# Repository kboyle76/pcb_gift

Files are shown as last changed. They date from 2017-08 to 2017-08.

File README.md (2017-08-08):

# pcb_gift

This is a soldering kit for to be distributed at the Playa Circuit Booogie Camp at Burning Man 2017. Our goal was to design a soldering kit that does something a little bit more interesting than simply blinking lights while still costing less than a few dollars each. Only one color LED is initally lit after assembling the kit, and users must find another person to "share" their color with and receive new colors in return to light up the rest of the LEDs! Each device can only receive one color from each other device, and communication happens using infrared light.

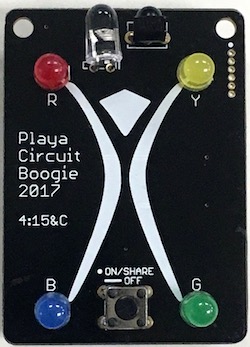
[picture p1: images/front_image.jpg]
Assembled Board Front
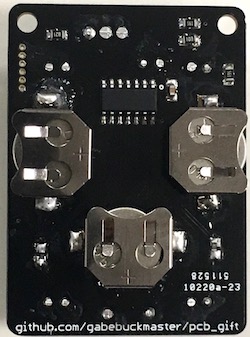
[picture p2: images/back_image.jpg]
Assembled Board Back
 

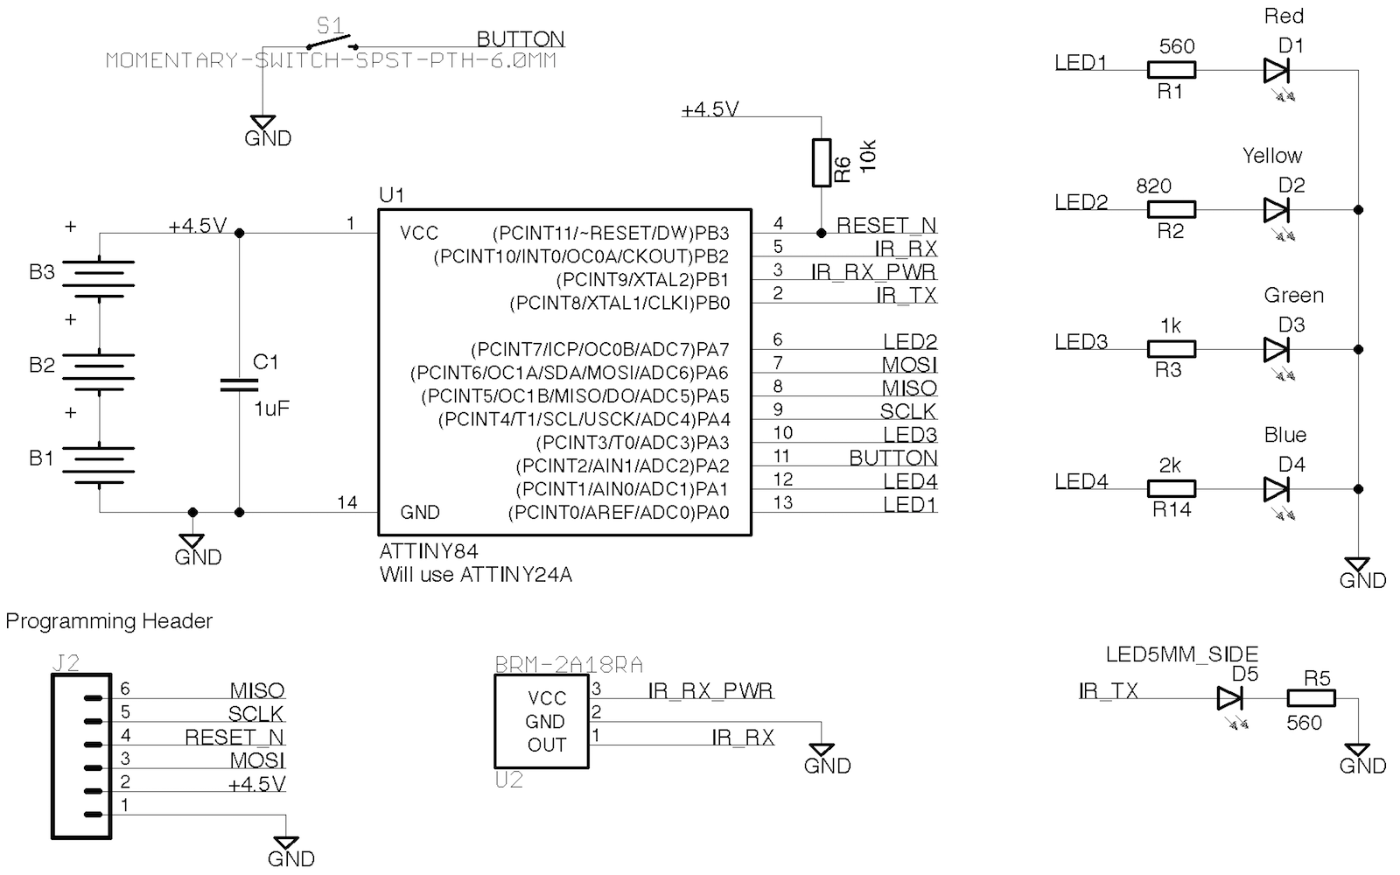
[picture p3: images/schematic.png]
Schematic


### SMT Pre-assembly Notes
The surface mount components will be pre-populated to facilitate assembly at the Playa.
- The surface mount battery holders are a bit weak and tend to pop off the circuit board, sometimes bringing the pad with them. You may want to further secure them with a dab of epoxy.
- For aesthetic reasons, surface mount component names are not included in the bottom silkscreen. The component locations are shown below for your convenience. 

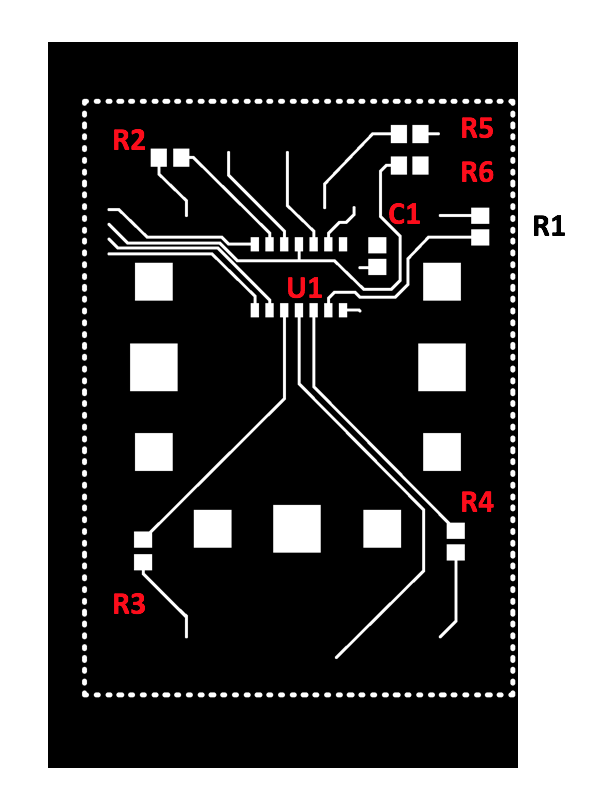
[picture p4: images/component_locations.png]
Component Locations


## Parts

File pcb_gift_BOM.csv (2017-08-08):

Reference | Quantity | Description | Manufacturer | Part Number | Cost @ qty 100 | Extended cost | Notes
U1 | 1 | 8 bit microcontroller -12 GPIO, 14 SOIC | Microchip | ATTINY44A-SSU | 0.618 | 61.8 | Digikey
U2 | 1 | 38 kHz IR receiver | Vishay | TSOP38338 | 0.6 | 60 | Digikey
C1 | 1 | 1uF 0805 ceramic capacitor X5R 6.3V | Generic |  | 0.0093 | 0.93 | Digikey
S1 | 1 | Tactile pushbutton | Generic |  | 0.04 | 8 | Aliexpress
R1, R5 | 2 | 5% 0805 Resistor 560 Ohms | Generic |  | 0.0067 | 1.34 | Digikey
R2 | 1 | 5% 0805 Resistor 820 Ohms | Generic |  | 0.0067 | 0.67 | Digikey
R3 | 1 | 5% 0805 Resistor 1.2k Ohms | Generic |  | 0.0067 | 0.67 | Digikey
R4 | 1 | 5% 0805 Resistor 680 Ohms | Generic |  | 0.0067 | 0.67 | Digikey
R6 | 1 | 5% 0805 Resistor 10k Ohms | Generic |  | 0.0067 | 0.67 | Digikey
D1 | 1 | 5mm Red Led | Generic |  | 0.0181 | 1.81 | Aliexpress
D2 | 1 | 5mm Yellow Led | Generic |  | 0.0181 | 1.81 | Aliexpress
D3 | 1 | 5mm Green Led | Generic |  | 0.0181 | 1.81 | Aliexpress
D4 | 1 | 5mm Blue Led | Generic |  | 0.0181 | 1.81 | Aliexpress
D5 | 1 | IR LED transmitter | Generic |  | 0.0181 | 1.81 | Aliexpress
B1-3 | 3 | Battery holder | Keystone | 2996 | 0.20492 | 61.476 | Digikey
N/A | 3 | LR44 battery |  |  | 0.0788 | 23.64 | Amazon

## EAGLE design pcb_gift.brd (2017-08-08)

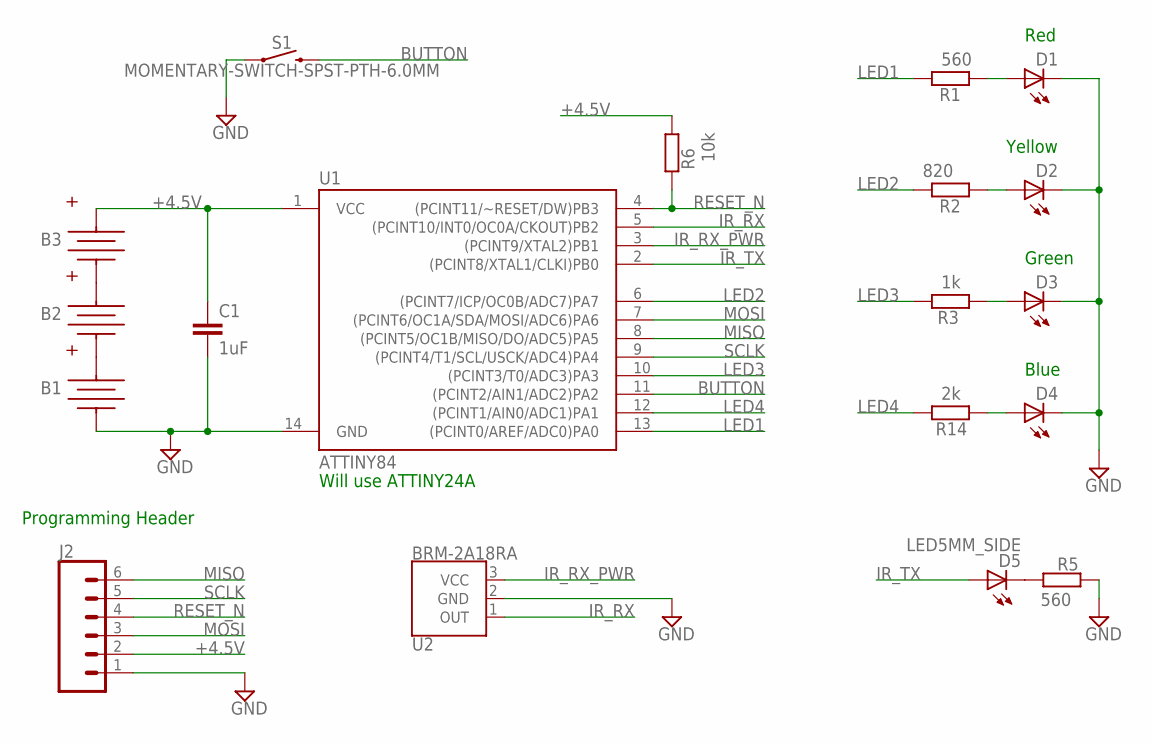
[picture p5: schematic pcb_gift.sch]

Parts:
B1, B2, B3: KEYSTONE_2996
C1: 1uF; C0805
D1, D2, D3, D4: LED5MM
D5: LED5MM_SIDE
J2: CONN_061.27MM; 1X06_1.27MM
R1, R5: 560; R0805
R2: 820; R0805
R3: 1k; R0805
R6: 10k; R0805
R14: 2k; R0805
S1: MOMENTARY-SWITCH-SPST-PTH-6.0MM; TACTILE_SWITCH_PTH_6.0MM
U1: ATTINY84; SO14
U2: BRM-2A18RA; BRM-2508

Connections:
+4.5V: B3.POSA (POS), B3.POSB (POS), C1.1, J2.2, R6.2, U1.1 (VCC)
BUTTON: S1.3 (2), U1.11 ((PCINT2/AIN1/ADC2)PA2)
GND: B1.NEG, C1.2, D1.K (C), D2.K (C), D3.K (C), D4.K (C), J2.1, R5.1, S1.1, U1.14 (GND), U2.2 (GND)
IR_RX: U1.5 ((PCINT10/INT0/OC0A/CKOUT)PB2), U2.1 (OUT)
IR_RX_PWR: U1.3 ((PCINT9/XTAL2)PB1), U2.3 (VCC)
IR_TX: D5.A, U1.2 ((PCINT8/XTAL1/CLKI)PB0)
LED1: R1.1, U1.13 ((PCINT0/AREF/ADC0)PA0)
LED2: R2.1, U1.6 ((PCINT7/ICP/OC0B/ADC7)PA7)
LED3: R3.1, U1.10 ((PCINT3/T0/ADC3)PA3)
LED4: R14.1, U1.12 ((PCINT1/AIN0/ADC1)PA1)
MISO: J2.6, U1.8 ((PCINT5/OC1B/MISO/DO/ADC5)PA5)
MOSI: J2.3, U1.7 ((PCINT6/OC1A/SDA/MOSI/ADC6)PA6)
unnamed: D1.A, R1.2
unnamed: B1.POSA (POS), B1.POSB (POS), B2.NEG
unnamed: B2.POSA (POS), B2.POSB (POS), B3.NEG
unnamed: D4.A, R14.2
unnamed: D3.A, R3.2
unnamed: D2.A, R2.2
unnamed: D5.K (C), R5.2
RESET_N: J2.4, R6.1, U1.4 ((PCINT11/~RESET/DW)PB3)
SCLK: J2.5, U1.9 ((PCINT4/T1/SCL/USCK/ADC4)PA4)

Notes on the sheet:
Will use ATTINY24A
Programming Header
Red
Yellow
Green
Blue

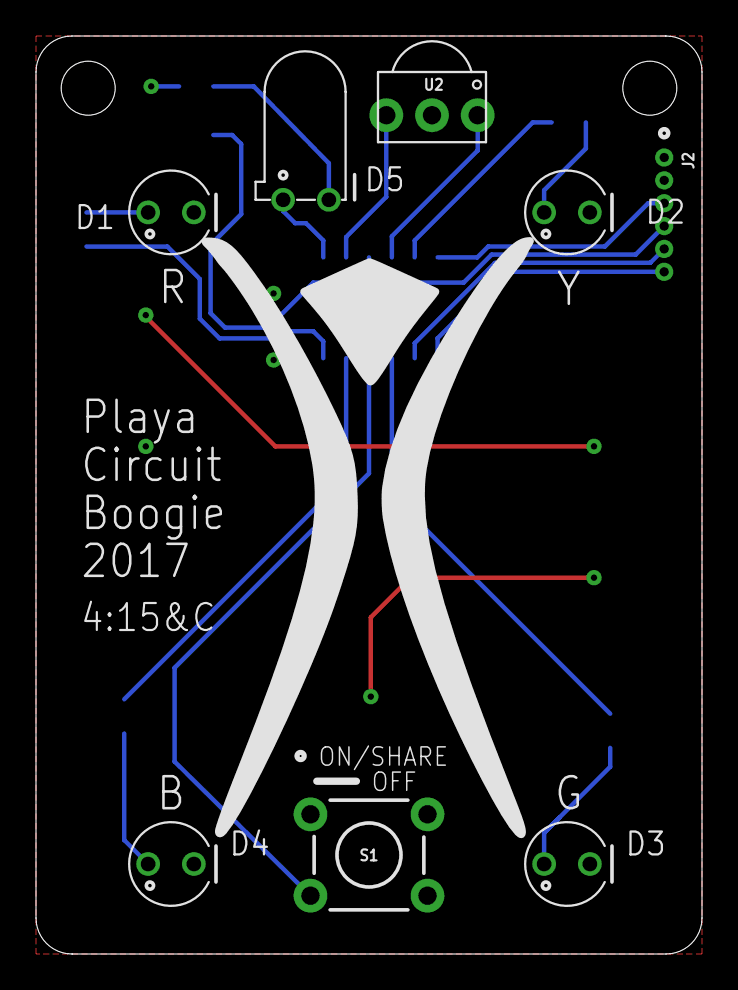
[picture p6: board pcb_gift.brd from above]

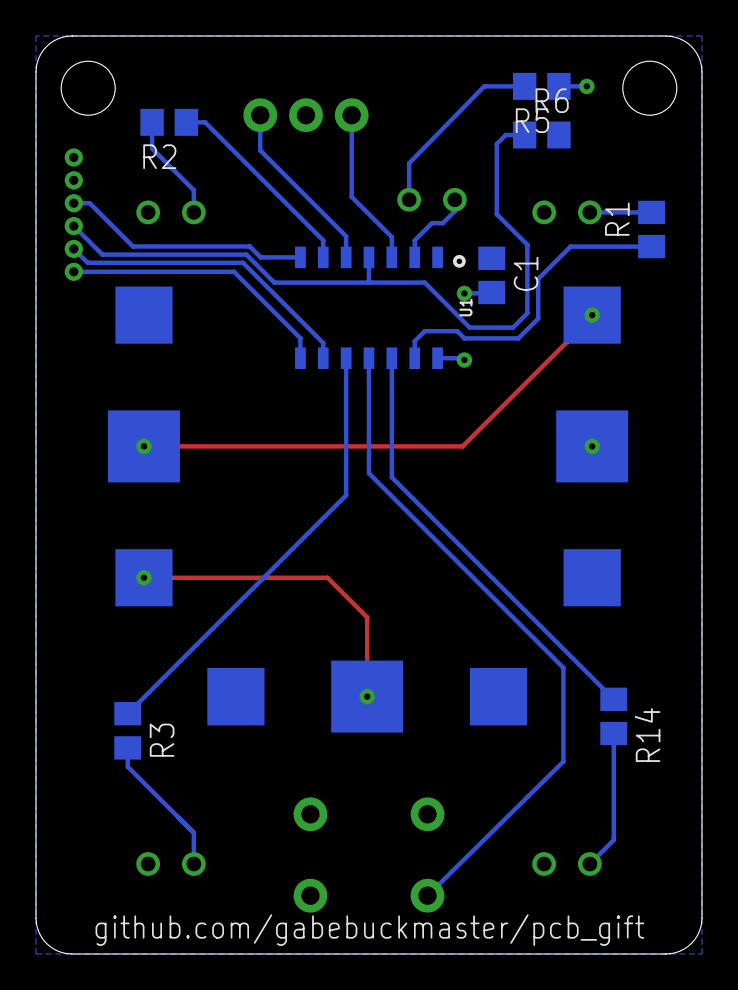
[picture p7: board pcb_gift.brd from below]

Board: 2 copper layers, 37.0 x 51.0 mm, 19 parts (11 on the bottom side), 21 nets.

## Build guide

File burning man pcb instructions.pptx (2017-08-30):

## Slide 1

Playa Circuit Boogie

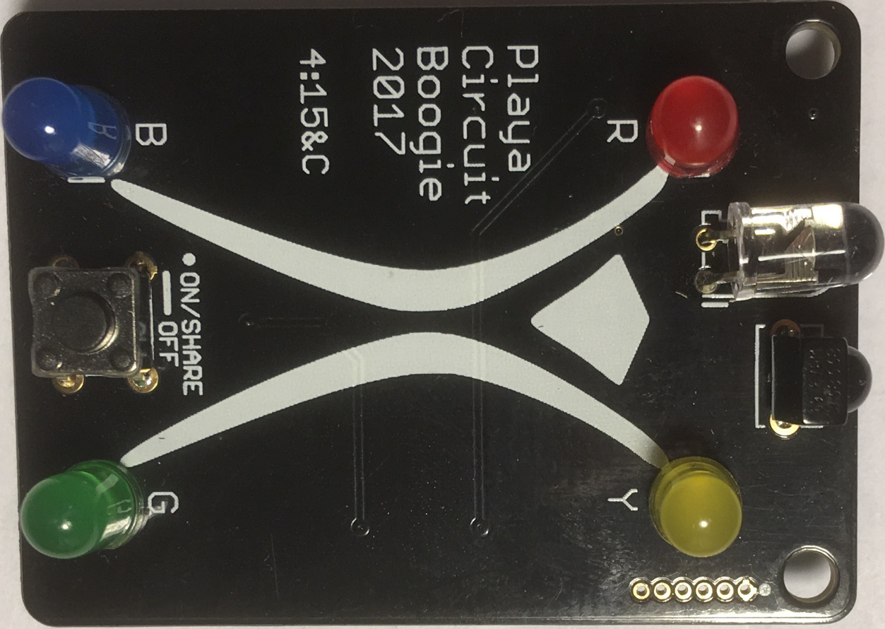
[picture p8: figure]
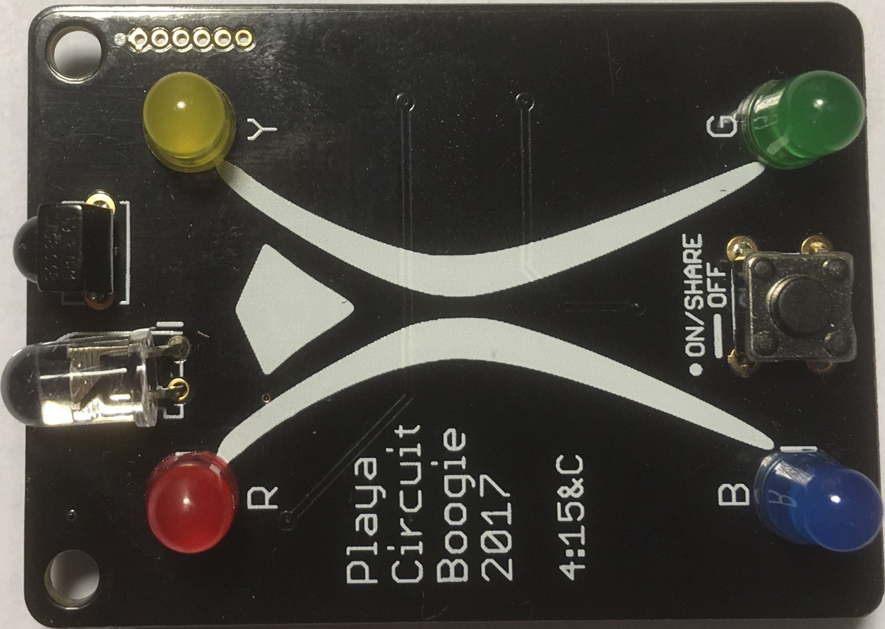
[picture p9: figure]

These instructions will help you solder together your very own PCB color widget so you can collect all four colors and light up the Man!
Just like a puzzle box, the picture above shows the final product, follow the instructions on the back and refer to this picture to put it together.
Once you’re done, and pop in the batteries, the lights should start flashing, press the button once to get your first color. Then:
- Find someone with a color you don’t yet have
- Point the clear and black LEDs facing outward on the two PCBs towards each other (like above) and press the buttons once at the same time
- You’ll get a color you don’t have that your new friend does. If multiple colors blink, then you don’t have any of those: press the button once to decide which one you get
- If you have a color your new friend doesn’t have, they’ll get that color
- You can only trade colors with a person once! If you try again, your PCB will flash the color you got from them already to remind you
- Hold the button briefly until the lights go out to turn off. Press once to turn back on. Save it for the nighttime! If the batteries die, it will still remember what colors you have, so come back around and see if we have spares
- If something goes terribly wrong, hold the button for about 30 seconds, until the lights start flashing again. This will reset you all the way back to the default
- If you love this project and want to check out how we did it, follow the link printed on the back of the PCB when you get home
Have fun and try to collect all the colors (and three new friends)!

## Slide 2

1
Start with the clear LED, this is the IR transmitter. Slot it into the correct holes (see tip below), and bend it over 90 degrees to face out, like the outline shows. Solder this from the back.
Tip: the symbols on the board show a dot for where the longer leg goes, and a flat bar that corresponds to the flat edge of the LED.

Front

2
Second, solder on the IR receiver. The bump should face outward. If it ends up crooked, gently bend it to be straight up and down.

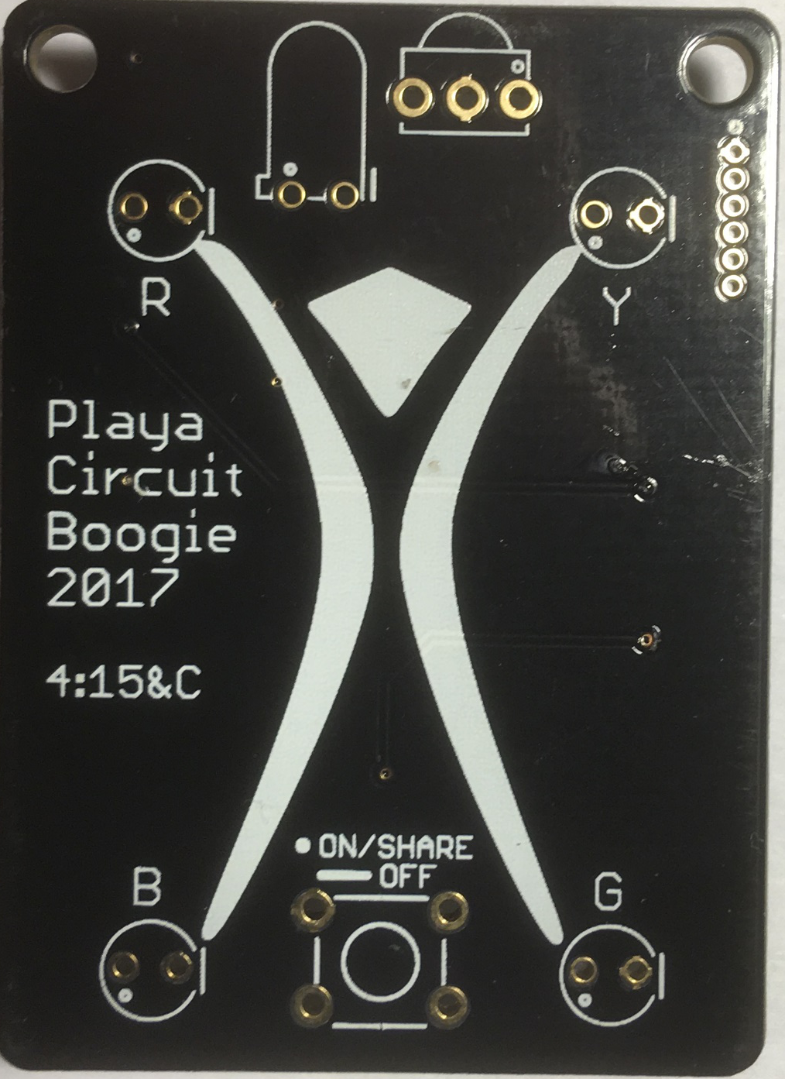
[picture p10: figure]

3
Third, solder the button. It has four legs and only fits on in one orientation: with the legs on the left and right sides, not the top and bottom sides. The bottom two connections are mandatory, the top two are optional.

4
Fourth, put each colored LED in its corresponding place, R – Red, Y – Yellow, B – Blue, G – Green. Pay attention to the tip above to get them in the right orientation. If you mix and match the positions, some LEDs may be brighter or dimmer, or not turn on at all!

5
Clip off the ends of the legs at the base while firmly holding on: avoid eye damage and MOOP from flying parts! Insert three batteries into the metal holders on the back. The lights should start flashing, press the button to get your first color!

Back

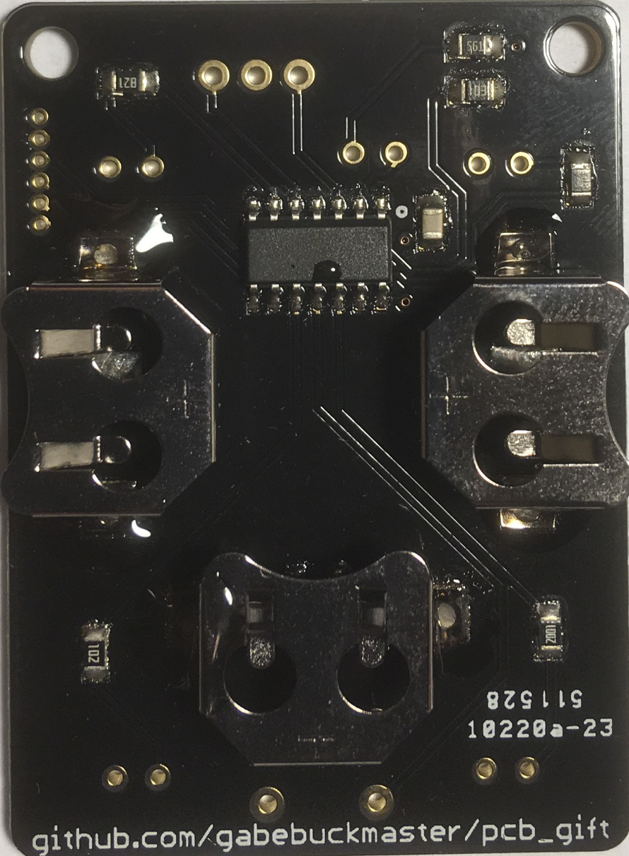
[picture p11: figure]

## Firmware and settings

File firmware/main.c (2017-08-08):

#include <avr/io.h>
#include <avr/interrupt.h>
#include <avr/sleep.h>
#include <avr/wdt.h>

#define IR_RX_TIMEOUT 20000

// Port A Pins
#define RED_LED 0
#define YELLOW_LED 7
#define GREEN_LED 3
#define BLUE_LED 1

#define RED_LED_COMM 0
#define YELLOW_LED_COMM 2
#define GREEN_LED_COMM 3
#define BLUE_LED_COMM 1

#define BUTTON 2


// Port B Pins
#define IR_TX 0
#define IR_RX_POWER 1
#define IR_RX 2


uint8_t my_colors = 0;
uint16_t my_id = 0;
uint16_t red_source_id = 0;
uint16_t green_source_id = 0;
uint16_t blue_source_id = 0;
uint16_t yellow_source_id = 0;


void stop_timer(void)
{
    cli();
    TCCR1A = 0;
    TCCR1B = 0;
    TIMSK1 = 0;
    sei();
}

void EEPROM_write(uint8_t address, uint8_t data)
{
    /* Wait for completion of previous write */
    while(EECR & (1<<EEPE));
    /* Set Programming mode */
    EECR = (0<<EEPM1)|(0<<EEPM0);
    /* Set up address and data registers */
    EEAR = address;
    EEDR = data;
    /* Write logical one to EEMPE */
    EECR |= (1<<EEMPE);
    /* Start eeprom write by setting EEPE */
    EECR |= (1<<EEPE);
}

uint8_t EEPROM_read(uint8_t address) {
    /* Wait for completion of previous write */
    while(EECR & (1<<EEPE));
    /* Set up address register */
    EEAR = address;
    /* Start eeprom read by writing EERE */
    EECR |= (1<<EERE);
    /* Return data from data register */
    return EEDR;
}

void erase_state(void)
{
    for(uint8_t i = 0; i < 11; i++)
    {
        EEPROM_write(i, 0xFF);
    }
}

void save_state(void)
{
    EEPROM_write(0, my_colors);
    EEPROM_write(1, my_id>>8);
    EEPROM_write(2, my_id);
    EEPROM_write(3, red_source_id>>8);
    EEPROM_write(4, red_source_id);
    EEPROM_write(5, green_source_id>>8);
    EEPROM_write(6, green_source_id);
    EEPROM_write(7, blue_source_id>>8);
    EEPROM_write(8, blue_source_id);
    EEPROM_write(9, yellow_source_id>>8);
    EEPROM_write(10, yellow_source_id);
}

void restore_state(void)
{
    my_colors = EEPROM_read(0);
    my_id = (((uint16_t)EEPROM_read(1))<<8) + EEPROM_read(2);
    red_source_id = (((uint16_t)EEPROM_read(3))<<8) + EEPROM_read(4);
    green_source_id = (((uint16_t)EEPROM_read(5))<<8) + EEPROM_read(6);
    blue_source_id = (((uint16_t)EEPROM_read(7))<<8) + EEPROM_read(8);
    yellow_source_id = (((uint16_t)EEPROM_read(9))<<8) + EEPROM_read(10);
}

void delay(uint16_t ms)
{
    set_sleep_mode(SLEEP_MODE_IDLE);
    sei();
    for(uint16_t i = 0; i < ms/16; i++)
    {
        WDTCSR |= (1<<WDIE);
        sleep_enable();
        sleep_mode();
    }
    WDTCSR &= ~(1<<WDIE);
}

void delay_100us(uint16_t t)
{
    for (uint16_t i = 0; i < t; i++)
    {
        for(uint16_t j = 0; j < 91; j++)
        {
            __asm__ __volatile__ ("nop");
        }
    }
}

uint8_t roulette(uint8_t options)
{
    uint8_t led = (1<<BLUE_LED);
        
    //button might still be down from reset - wait for it to be released
    while(!(PINA & (1<<BUTTON)))
    {
        PORTA |= ((1<<BLUE_LED)|(1<<RED_LED)|(1<<YELLOW_LED)|(1<<GREEN_LED));
    }
    
    // display roulette pattern until button pressed
    while(PINA & (1<<BUTTON))
    {
        switch (led)
        {
            case (1<<BLUE_LED):
                led = (1<<RED_LED);
                break;
            case (1<<RED_LED):
                led = (1<<YELLOW_LED);
                break;
            case (1<<YELLOW_LED):
                led = (1<<GREEN_LED);
                break;
            case (1<<GREEN_LED):
                led = (1<<BLUE_LED);
                break;
        }
        if(led & options)
        {
            PORTA &= ~((1<<BLUE_LED)|(1<<RED_LED)|(1<<YELLOW_LED)|(1<<GREEN_LED));
            PORTA |= led;
            delay(50);
        }
    }
    // wait for button to be released and debounce before returning
    while(!(PINA & (1<<BUTTON)));
    delay(100);
    return led;
}

void ir_tx_bit(uint8_t bit)
{
    cli();
    TCNT1 = 0;
    TCCR1A = 0;
    TCCR1B = (1 << CS10);
    OCR1A = 102;
    TCCR1B |= (1<<WGM12);
    TIMSK1 = 1<<OCIE1A;
    sei();
    
    if(bit)
    {
        delay_100us(13);
        stop_timer();
        PORTB &= ~(1<<IR_TX);
        delay_100us(7);
    }
    else
    {
        delay_100us(7);
        stop_timer();
        PORTB &= ~(1<<IR_TX);
        delay_100us(13);
    }
}

void ir_wait_tx(uint16_t time)
{
    for(uint8_t i = 0; i < time; i++)
    {
        delay_100us(1);
        if(!(PINB & (1<<IR_RX)))
        {
            i = 0;
        }
    }
}

void ir_tx(uint32_t tx_data, uint8_t n_bits)
{
    for(uint8_t i = 0; i < n_bits; i++)
    {
        if(tx_data & 1)
        {
            ir_tx_bit(1);
        }
        else
        {
            ir_tx_bit(0);
        }
        tx_data = tx_data >> 1;
    }
}

uint32_t ir_rx(uint8_t n_bits)
{
    uint32_t rx_data = 0;
    uint8_t set_bit = 0;
    uint8_t count = 0;
    uint16_t timer = 0;
    
    
    for(uint8_t i = 0; i < n_bits; i++)
    {
        while((PINB & (1<<IR_RX)))
        {
            if (timer > IR_RX_TIMEOUT)
            {
                return 0;
            }
            delay_100us(1);
            timer++;
        }
        while(!(PINB & (1<<IR_RX)))
        {
            if(timer > IR_RX_TIMEOUT)
            {
                return 0;
            }
            delay_100us(1);
            count++;
            timer++;
        }
        if(count > 15) // measured 19 for long, 11 for short
        {
            rx_data |= (((uint32_t)1)<<set_bit);
        }
        set_bit += 1;
        count = 0;
    }
    return rx_data;
}

void angry_blink(uint8_t led)
{
    for(uint8_t i = 0; i < 5; i++)
    {
        PORTA &= ~((1<<BLUE_LED)|(1<<RED_LED)|(1<<YELLOW_LED)|(1<<GREEN_LED));
        delay(100);
        PORTA |= (1<<led);
        delay(100);
    }
}


void exchange_colors(void)
{
    // turn on IR receiver, make sure IR tramsitter is off
    PORTB |= (1<<IR_RX_POWER);
    PORTB &= ~(1<<IR_TX);

    uint32_t tx_buffer = 0;
    
    
    //pack the colors into 4 bits
    uint8_t my_colors_comm = 0;
    if(my_colors & (1<<YELLOW_LED))
    {
        my_colors_comm |= (1<<YELLOW_LED_COMM);
    }
    
    if(my_colors & (1<<RED_LED))
    {
        my_colors_comm |= (1<<RED_LED_COMM);
    }
    
    if(my_colors & (1<<GREEN_LED))
    {
        my_colors_comm |= (1<<GREEN_LED_COMM);
    }
    
    if(my_colors & (1<<BLUE_LED))
    {
        my_colors_comm |= (1<<BLUE_LED_COMM);
    }
    
    uint8_t my_checksum = ((my_colors_comm)^(my_id)^(my_id>>4)^(my_id>>8)^(my_id>>12)) & 0x0F;
    tx_buffer = my_colors_comm + (((uint32_t)my_id) << 4) + (((uint32_t)my_checksum) << 20);
    
    delay(200); //let receiver stabilize
    
    //wait for a few bit periods of silence
    ir_wait_tx(100);
    
    // transmit
    ir_tx(tx_buffer, 24);
    
    //receive with about .5s timeout
    uint32_t rx_buffer = ir_rx(24);
    
    //return if receive timed out
    if(rx_buffer == 0)
    {
        // turn off IR receiver and make sure IR tramsitter is off
        PORTB &= ~((1<<IR_RX_POWER)|(1<<IR_TX)) ;
        return;
    }
    
    delay(20);
    
    //transmit again
    ir_tx(tx_buffer, 24);
    
    // turn off IR receiver and make sure IR tramsitter is off
    PORTB &= ~((1<<IR_RX_POWER)|(1<<IR_TX)) ;
    
    uint8_t rx_colors_comm = (uint8_t) (rx_buffer & 0x0F);
    uint16_t rx_id = (uint16_t) ((rx_buffer >> 4) & 0xFFFF);
    uint8_t checksum_rx = ((rx_buffer >> 20) & 0x0F);
    uint8_t checksum_calculated = ((rx_colors_comm)^(rx_id)^(rx_id>>4)^(rx_id>>8)^(rx_id>>12)) & 0x0F;
    
    // abort if the data seems mangled
    if(checksum_rx != checksum_calculated)
    {
        return;
    }
    
    uint8_t rx_colors = 0;
    //unpack color data
    if(rx_colors_comm & (1<<YELLOW_LED_COMM))
    {
        rx_colors |= (1<<YELLOW_LED);
    }
    
    if(rx_colors_comm & (1<<RED_LED_COMM))
    {
        rx_colors |= (1<<RED_LED);
    }
    
    if(rx_colors_comm & (1<<GREEN_LED_COMM))
    {
        rx_colors |= (1<<GREEN_LED);
    }
    
    if(rx_colors_comm & (1<<BLUE_LED_COMM))
    {
        rx_colors |= (1<<BLUE_LED);
    }
    
    // check to see if we've already received a color from this device
    if(rx_id == red_source_id)
    {
        angry_blink(RED_LED);
        return;
    }
    if(rx_id == green_source_id)
    {
        angry_blink(GREEN_LED);
        return;
    }
    if(rx_id == blue_source_id)
    {
        angry_blink(BLUE_LED);
        return;
    }
    if(rx_id == yellow_source_id)
    {
        angry_blink(YELLOW_LED);
        return;
    }
    
    rx_colors &= ~my_colors; // keep only the colors we don't already have
    
    // if we already have all of the colors they have, return
    if (rx_colors == 0)
    {
        return;
    }
    
    uint8_t new_color = 0;
    // if there's only one new one, go ahead and assign it
    if (rx_colors == (1<<RED_LED) || rx_colors == (1<<GREEN_LED) || rx_colors == (1<<YELLOW_LED) || rx_colors == (1<<BLUE_LED))
    {
        new_color |= rx_colors;
    }
    else
    { // if we received multiple colors we don't have, let the user choose
        new_color = roulette(rx_colors);
    }
    my_colors |= new_color;
    
    // record the sender of this new color
    switch(new_color)
    {
        case (1<<RED_LED):
            red_source_id = rx_id;
            break;
        case (1<<GREEN_LED):
            green_source_id = rx_id;
            break;
        case (1<<BLUE_LED):
            blue_source_id = rx_id;
            break;
        case (1<<YELLOW_LED):
            yellow_source_id = rx_id;
            break;
    }
}


int main(void)
{
    // Set output pins to output mode
    DDRA |= (1<<RED_LED)|(1<<YELLOW_LED)|(1<<GREEN_LED)|(1<<BLUE_LED);
    DDRB |= (1<<IR_RX_POWER)|(1<<IR_TX);

    //Enable pullup on button
    PORTA |= (1<<BUTTON);
    
    ADCSRA &= ~(1<<ADEN); //draws significant current in sleep mode if not disabled
    
    // Check if this is the first run (blank EEPROM will read 0xFF)
    my_colors = EEPROM_read(0);
    if(my_colors == 0xFF) // it's the first run
    {
        //start the timer with no interrupts
        cli();
        TCCR1A = 0;
        TCCR1B = (1 << CS10);
        TIMSK1 = 0;
        sei();
        
        // Have user choose an inital color
        my_colors = roulette((1<<RED_LED)|(1<<YELLOW_LED)|(1<<GREEN_LED)|(1<<BLUE_LED));
        
        // stop timer to get a random 16 bit id
        stop_timer();
        my_id = TCNT1;
        if(my_id == 0)
            my_id = 1;
        
        save_state();
    }
    else // it's not the first run
    {
        restore_state();
    }
    
    uint16_t button_down_time = 0;
    
    // main loop
    while(1)
    {
        PORTA &= ~((1<<BLUE_LED)|(1<<RED_LED)|(1<<YELLOW_LED)|(1<<GREEN_LED));
        PORTA |= (((1<<BLUE_LED)|(1<<RED_LED)|(1<<YELLOW_LED)|(1<<GREEN_LED)) & my_colors);
        
        // things that happen on button release
        if((PINA & (1<<BUTTON)) && (button_down_time != 0))
        {
            //exchange colors after a short press
            if (button_down_time < 50)
            {
                exchange_colors();
                save_state();
                button_down_time = 0;
            }
            
            // actually sleep after a long press is released
            if(button_down_time >= 50)
            {
                //debounce
                PORTA &= ~((1<<BLUE_LED)|(1<<RED_LED)|(1<<YELLOW_LED)|(1<<GREEN_LED));
                delay(200);
                GIMSK |= (1 << PCIE0);
                PCMSK0 |= (1 << PCINT2);
                sei();
                set_sleep_mode(SLEEP_MODE_PWR_DOWN);
                sleep_enable();
                sleep_mode();
                // pin change interrupt on button enabled - short press wakes
                sleep_disable();
                GIMSK &= ~(1 << PCIE0);
                PCMSK0 &= ~(1 << PCINT2);
                button_down_time = 0;
                
                PORTA |= (((1<<BLUE_LED)|(1<<RED_LED)|(1<<YELLOW_LED)|(1<<GREEN_LED)) & my_colors);
                // wait for button release and debounce
                while(!(PINA & (1<<BUTTON)));
                delay(200);
            }
        }
        
        // things that happen while button is held down
        if(!(PINA & (1<<BUTTON)))
        {
            button_down_time++;
            
            // appear to sleep after a long press
            if(button_down_time >= 50)
            {
                PORTA &= ~((1<<BLUE_LED)|(1<<RED_LED)|(1<<YELLOW_LED)|(1<<GREEN_LED));
            }
            
            // reset after a very long press
            if(button_down_time > 500)
            {
                button_down_time = 0;
                my_colors = 0;
                red_source_id = 0;
                green_source_id = 0;
                blue_source_id = 0;
                yellow_source_id = 0;
                erase_state();
                
                cli();
                TCCR1A = 0;
                TCCR1B = (1 << CS10);
                TIMSK1 = 0;
                sei();
                
                my_colors = roulette((1<<RED_LED)|(1<<YELLOW_LED)|(1<<GREEN_LED)|(1<<BLUE_LED));
                
                stop_timer();
                my_id = TCNT1;
                if(my_id == 0)
                    my_id = 1;
                
                save_state();
            }
            
        }
        
        delay(16);
    }
}

ISR(TIM1_COMPA_vect)
{
    PORTB ^= (1<<IR_TX);
}

ISR(WDT_vect) {
    sleep_disable();
}

ISR(PCINT0_vect) {
    sleep_disable();
}

ISR(PCINT1_vect) {
    sleep_disable();
}

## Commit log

2017-07-26 Initial commit
    Board and schematic are finalized for this revision. Firmware still
    needs to be updated for this version of the PCB.
    [pcb_gift.brd, pcb_gift.sch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]
2017-07-26 Fixed gerber file names
    Gerbers still had an old file name and have now been updated.
    [pcb_gift.drills.xln]
2017-08-08 updated code for new revision and cleaned things up
    - added bom
    - updated firmware for this version
    - firmware has deeper sleep mode
    - added scripts to compile/upload to board
    - added .gitignore
    - updated readme
    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
    [pcb_gift.brd, pcb_gift.sch, pcb_gift_BOM.csv]
2017-08-30 Adding instructions
    Adds pdf and powerpoint version of instruction sheet showing assembly and operation.

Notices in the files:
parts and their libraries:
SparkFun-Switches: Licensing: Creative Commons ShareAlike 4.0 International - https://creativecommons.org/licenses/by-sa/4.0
